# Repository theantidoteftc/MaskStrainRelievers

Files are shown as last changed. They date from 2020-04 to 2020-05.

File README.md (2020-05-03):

# MaskStrainRelievers
Here is theantidoteftc's design for a Mask Strain Reliever to be worn in the back of the head while utilizing surgical masks or any other face covering that typically catches behind the ear.  The strain reliever redirects the strain on the back of the ear to behind the head, allowing for increase comfort while healthcare workers work for prolonged periods of time.  We are planning on submitting for NIH review.  Let me know if you have any suggestions or comments!

Rafts:
No

Supports:
No

Walls:
4

Resolution:
0.3mm Layer Height

Infill:
Doesn't Matter

Filament_brand:
Hatchbox (Anything really)

Filament_material:
PLA or PETG

## Changelog
##### Update to 3MF (05/03/2020)
'Mask Strain Reliever V9 (Thicker) 10x.3MF' is a 3MF File with 10 MSRs fitted on a glass Ender 3 Pro bed. This will likely work on stock Ender 3s as well.

##### Version 9 (04/12/2020)

Based on local feedback, the thickness of the model has increased by 0.3mm (equal to one layer). Due to the variability in printers and filament flexibilities, there is now a Thicker and Thinner option for you to pick and choose what works best for you. The Thinner option consists of 4 layers for the entire model. The Thicker option consists of 4 layers for the base, and an additional layer on the prongs to increase rigidity. I recommend printing both files and testing the flexibility of both before choosing a certain file. STLs are included as usual, and 3MFs designed specifically for the Ender 3 are now included, making stuff easier on the manufacturing side. Happy printing!

##### Version 7 (04/10/2020)

Prongs are now more rounded at the end and fillets have a greater radius to decrease the chance of the prongs catching in hair.

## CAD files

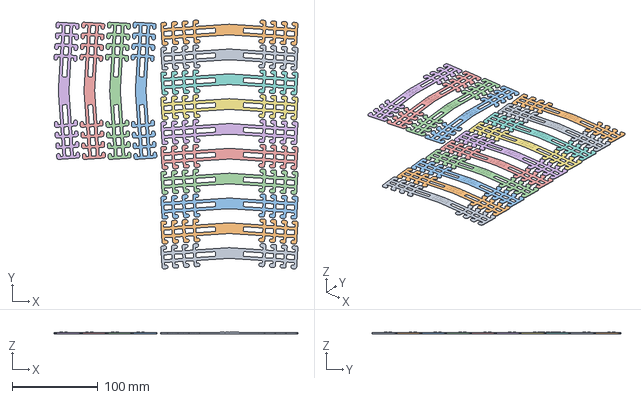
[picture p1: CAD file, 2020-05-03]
Experimental (CR10V2)/Mask String Reliever V9 CR10V2.3mf
285.0 x 290.6 x 1.80 mm

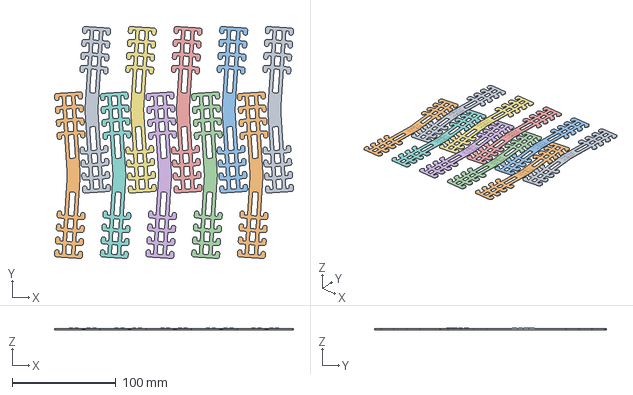
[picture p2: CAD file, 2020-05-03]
Mask String Reliever V9 (Thicker) 10x.3mf
230.1 x 223.3 x 1.92 mm

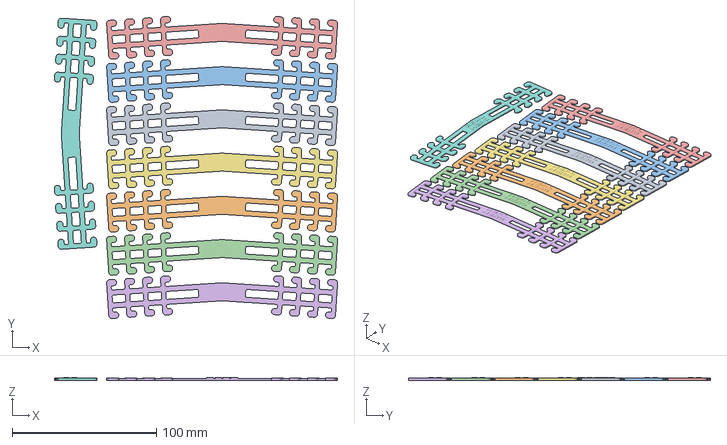
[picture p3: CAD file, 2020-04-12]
Mask String Reliever V9 Ender 3 (Thicker).3mf
196.6 x 209.6 x 1.80 mm

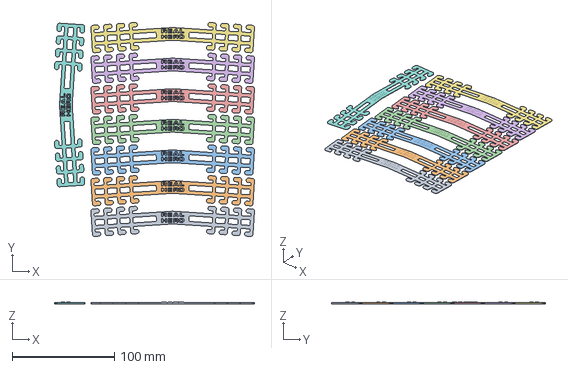
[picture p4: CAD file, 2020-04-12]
Mask String Reliever V9 Ender 3 (Thinner).3mf
196.0 x 209.6 x 1.80 mm

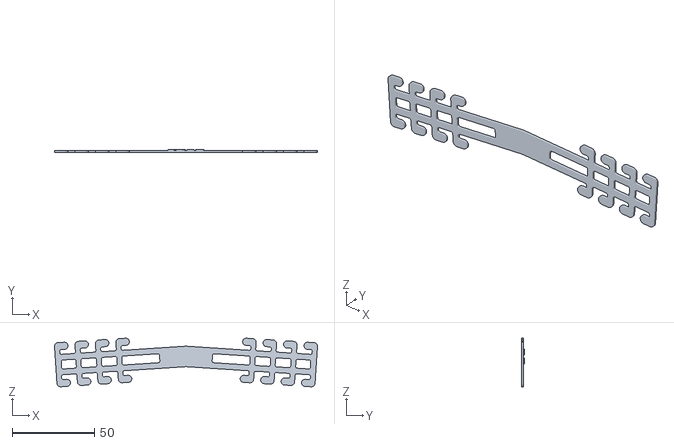
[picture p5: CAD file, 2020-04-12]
Mask String Reliever V9 (Thinner).STL
160.3 x 1.80 x 29.6

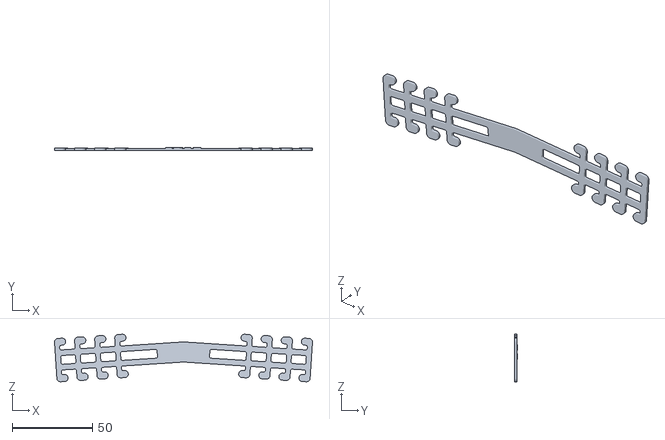
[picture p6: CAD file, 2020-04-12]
Mask String Reliever V9 (Thicker).STL
160.3 x 1.80 x 29.6

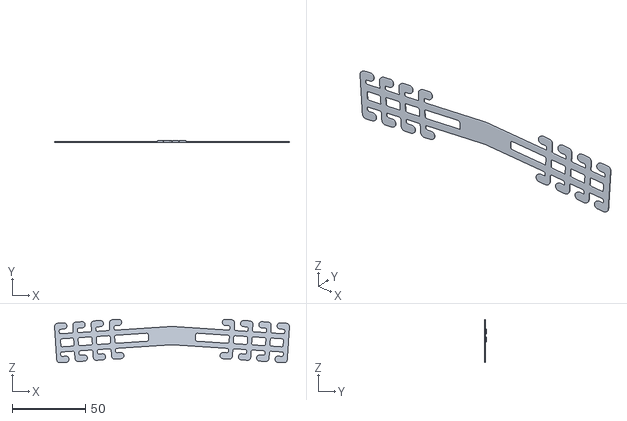
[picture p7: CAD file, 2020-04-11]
Mask String Reliever V7.STL
160.3 x 1.50 x 29.7

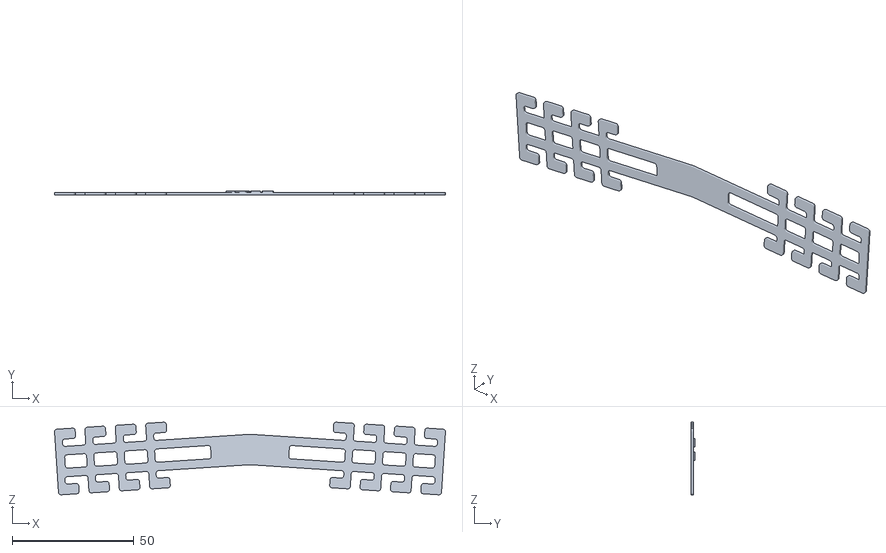
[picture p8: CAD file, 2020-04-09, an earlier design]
Old Versions/Mask String Reliever V6.STL
160.5 x 1.50 x 29.8

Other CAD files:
Old Versions/Mask String Reliever V9 Ender 3 Pro.3mf

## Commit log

2020-04-11 Add files via upload
    Version 7 of MSR
    [Mask String Reliever V7.STL]
2020-04-11 Create Folder to Store Old Versions
    [Mask String Reliever V6.STL]
2020-04-12 Mask String Reliever V9 Update + Now with a Thinner and Thicker Option
    [Mask String Reliever V7.STL, Mask String Reliever V9 (Thicker).STL, Mask String Reliever V9 (Thinner).STL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]
2020-04-18 Thinner Versions Removed For Clarity
    Thinner Versions have a tendency to buckle/bend/snap near the prongs - this issue is hard to recreate via the Thicker versions leading to the removal of this Thinner version.
    Please print the Thicker versions from now on!
    [Mask String Reliever V9 (Thinner).STL, Mask String Reliever V9 Ender 3 (Thinner).3mf]
2020-05-03 10 MSR for Ender 3 Pro Released
    [Mask String Reliever V9 (Thicker) 10x.3mf, Mask String Reliever V9 CR10V2.3mf, Mask String Reliever V9 Ender 3 (Thicker).3mf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]
